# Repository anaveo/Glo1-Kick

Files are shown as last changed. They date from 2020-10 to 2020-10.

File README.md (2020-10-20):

# Glo1-Kick

For more information regarding this project's Kickstarter page, please click [here](https://www.kickstarter.com/projects/omnitech/glo-a-hackable-arduino-based-rgb-led-strip-controller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).

Click [here](https://omanavekar.wixsite.com/ommakes/glo-rev-1) to access the project's main page on [omlabs.me](https://omanavekar.wixsite.com/ommakes)

Glo can be reprogrammed with customizable unique patterns via the Arduino interface. Switching between modes can be done by pressing two buttons on the right side of the board. Since Glo has usable GPIO ports available, LEDs can be controlled by adding external sensors, modules, or communication devices. Glo is also equipped with a hall effect sensor. This device can detect magnetic fields and can be used to change the LED pattern based on magnetic interaction. This can be used for several applications such as sensing if doors or drawers are open or detecting the speed of a bicycle wheel.

## Features
* 4 addressable RGB LED channels
* 1x Digital pin (D2), 8x Analog Pins (A0-A7), and Serial Transmission Pins (TX & RX). However, analog pins may be used as digital pins if necessary. These can be used to wire up other sensors and modules.
* 3x GND pins, 2x 5V pins, 2x 3.3V pins, 1x VIN (voltage supplied by power supply) pin, and 1x RESET pin.
* Open source Arduino-compatible microcontroller (Atmega 328p)
* FT232 USB to Serial converter chip. This chip is used on official Arduino boards and does not contain driver issues commonly found in clones (devices using the CH340G chip).
* Advanced Monolithic Systems AMS1117 Voltage Regulator for microcontroller
* Hall effect sensor. This sensor detects the presence of nearby magnets. For example, this allows for rotation based patterns if Glo is mounted on a bicycle tire.
* Mini USB serial programming port
* Power and status LEDs
* Mini USB 5V power port and terminal block 5-12V power port. Useful for 12V 3pin addressable LEDs
* A 1 amp thermal fuse has been added to the USB Power Port. This is a safety feature meant to prevent damage to your USB power supply as most USB devices have a maximum current   tolerance of 1 amp. In the case that more than 1 amp is drawn from your USB port, the fuse will open the circuit and will reset itself when less than an amp is drawn. If you     would like to bypass the fuse, you can remove it by desoldering the component (marked F1) or soldering a jumper connecting the component's two leads together.

## Compatible LED Types & Maximum LED Control
Glo is designed to work with addressable LEDs/LED strips such as Adafruit Neopixels (SK6812) and WS2812B LEDs (commonly found on addressable LED strips, matrices, etc).

Glo is designed to be powered either via 5V from its USB power port, or 5V from its screw terminal power port. However, the screw terminal power port can accept voltages between 5-12V, meaning addressable LEDs with higher voltages can be controlled using Glo. Glo does not support 4-pin 12V led strips. These strips are not individually addressable and contain an entirely different pinout.

Glo can safely control up to 240 individual LEDs, or 60 LEDs per channel. This allows for control of:

26 feet/8 meters of low-density strips (30 LEDs per meter)
13 feet/4 meters of medium-density strips (60 LEDs per meter)
5.5 feet/1.6 meters of high-density strips (144 LEDs per meter)

## Maximum Current Capability
While control is one thing, power distribution is another issue. Since standard Neopixel/WS2812B LEDs pull ~60mA of current each at maximum brightness (All Red, Green, and Blue sectors on full), 240 LEDs will require 14.4 amps at maximum. While Glo can handle this amount of current, it is not advised to run all 240 LEDs at maximum brightness continuously, as this can overheat both the LEDs and the controller.

It is recommended to keep current usage at 10 amps or below, to protect the electronics involved from overheating. Since most addressable LED projects utilize changing colors and animations, it is likely that this amount of current will never be sourced.

This means that the amount of LEDs that can be powered is dependant on the power supply you plan to use. Make sure that your power supply is capable of supplying the required current for your project before you turn the lights on!

## Important Connection Information
* **DO NOT** connect Glo's USB power port and its Power Terminal to a voltage source at the same time. This may damage the controller as well as both power supplies. 

* Glo has a feature in which it can be programmed while power is supplied through its USB power port or Power Terminal. This allows you to test LED patterns without having to unplug your power source.

* If you are powering Glo via the Power Terminal (2 pin green connector) when programming the device, connect your computer's USB cable to the **PROGRAM PORT ONLY**

    * Connecting your computer's USB to the power port will result in a dual voltage source and could damage your computer's USB port, as well as the controller.
    * All ports and their pinouts have been marked on the underside of the PCB.

* Please connect your LED strips and power supplies based on the pinouts given on the underside of the board. Incorrect wiring may lead to LED damage or failure.

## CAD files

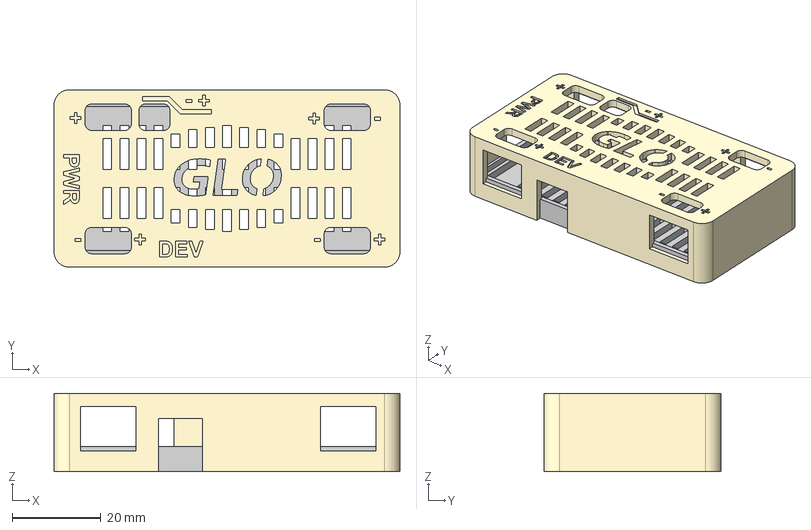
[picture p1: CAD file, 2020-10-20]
models/Case Glo Rev 1.step
78.0 x 40.0 x 17.6 mm

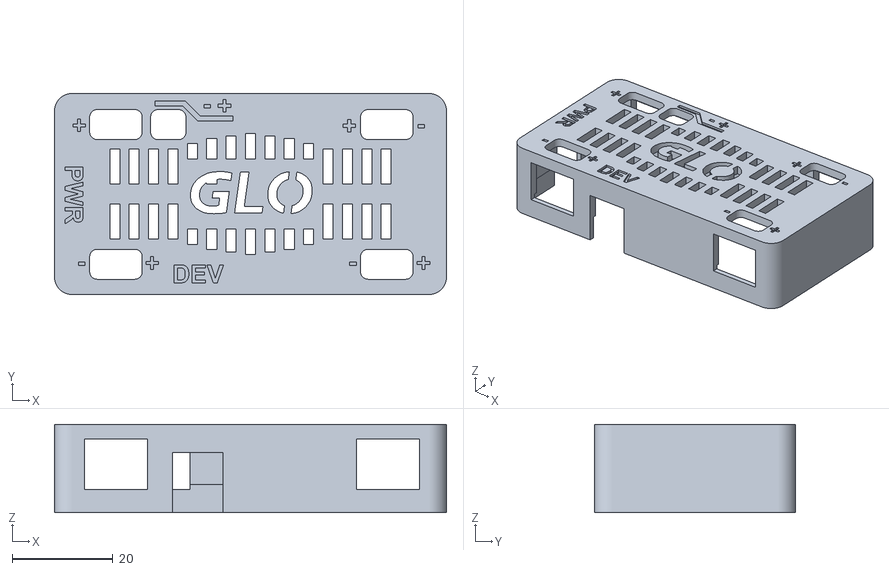
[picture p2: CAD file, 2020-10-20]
models/Glo Case Top.stl
78.0 x 40.0 x 17.6

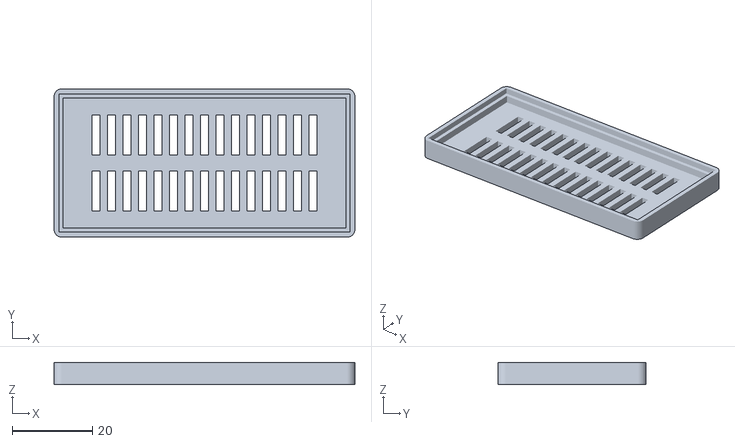
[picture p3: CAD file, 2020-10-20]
models/Glo Case Bottom.stl
75.0 x 37.0 x 5.60

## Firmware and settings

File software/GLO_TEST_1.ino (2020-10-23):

// A basic everyday NeoPixel strip test program.
// Modified for Glo Rev 1 - Om Anavekar

// NEOPIXEL BEST PRACTICES for most reliable operation:
// - Add 1000 uF CAPACITOR between NeoPixel strip's + and - connections.
// - MINIMIZE WIRING LENGTH between microcontroller board and first pixel.
// - NeoPixel strip's DATA-IN should pass through a 300-500 OHM RESISTOR.
// - AVOID connecting NeoPixels on a LIVE CIRCUIT. If you must, ALWAYS
//   connect GROUND (-) first, then +, then data.
// - When using a 3.3V microcontroller with a 5V-powered NeoPixel strip,
//   a LOGIC-LEVEL CONVERTER on the data line is STRONGLY RECOMMENDED.
// (Skipping these may work OK on your workbench but can fail in the field)

#include <Adafruit_NeoPixel.h>
#ifdef __AVR__
 #include <avr/power.h> // Required for 16 MHz Adafruit Trinket
#endif

// Which pin on the Arduino is connected to the NeoPixels?
// On a Trinket or Gemma we suggest changing this to 1:
#define LED_PIN    6
#define LED_PIN2   7
#define LED_PIN3   8
#define LED_PIN4   9

// How many NeoPixels are attached to the Arduino?
#define LED_COUNT 60

// Declare our NeoPixel strip object:
Adafruit_NeoPixel strip(LED_COUNT, LED_PIN, NEO_GRB + NEO_KHZ800);
Adafruit_NeoPixel strip2(LED_COUNT, LED_PIN2, NEO_GRB + NEO_KHZ800);
Adafruit_NeoPixel strip3(LED_COUNT, LED_PIN3, NEO_GRB + NEO_KHZ800);
Adafruit_NeoPixel strip4(LED_COUNT, LED_PIN4, NEO_GRB + NEO_KHZ800);
// Argument 1 = Number of pixels in NeoPixel strip
// Argument 2 = Arduino pin number (most are valid)
// Argument 3 = Pixel type flags, add together as needed:
//   NEO_KHZ800  800 KHz bitstream (most NeoPixel products w/WS2812 LEDs)
//   NEO_KHZ400  400 KHz (classic 'v1' (not v2) FLORA pixels, WS2811 drivers)
//   NEO_GRB     Pixels are wired for GRB bitstream (most NeoPixel products)
//   NEO_RGB     Pixels are wired for RGB bitstream (v1 FLORA pixels, not v2)
//   NEO_RGBW    Pixels are wired for RGBW bitstream (NeoPixel RGBW products)


// setup() function -- runs once at startup --------------------------------

void setup() {
  // These lines are specifically to support the Adafruit Trinket 5V 16 MHz.
  // Any other board, you can remove this part (but no harm leaving it):
#if defined(__AVR_ATtiny85__) && (F_CPU == 16000000)
  clock_prescale_set(clock_div_1);
#endif
  // END of Trinket-specific code.

  strip.begin();           // INITIALIZE NeoPixel strip object (REQUIRED)
  strip.show();            // Turn OFF all pixels ASAP
  strip.setBrightness(50); // Set BRIGHTNESS to about 1/5 (max = 255)
  strip2.begin();           // INITIALIZE NeoPixel strip object (REQUIRED)
  strip2.show();            // Turn OFF all pixels ASAP
  strip2.setBrightness(50);
  strip3.begin();           // INITIALIZE NeoPixel strip object (REQUIRED)
  strip3.show();            // Turn OFF all pixels ASAP
  strip3.setBrightness(50);
  strip4.begin();           // INITIALIZE NeoPixel strip object (REQUIRED)
  strip4.show();            // Turn OFF all pixels ASAP
  strip4.setBrightness(50);
}


// loop() function -- runs repeatedly as long as board is on ---------------

void loop() {
  // Fill along the length of the strip in various colors...
  colorWipe(strip.Color(255,   0,   0), 50); // Red
  colorWipe(strip.Color(  0, 255,   0), 50); // Green
  colorWipe(strip.Color(  0,   0, 255), 50); // Blue

  // Do a theater marquee effect in various colors...
  theaterChase(strip.Color(127, 127, 127), 50); // White, half brightness
  theaterChase(strip.Color(127,   0,   0), 50); // Red, half brightness
  theaterChase(strip.Color(  0,   0, 127), 50); // Blue, half brightness

  rainbow(10);             // Flowing rainbow cycle along the whole strip
  //theaterChaseRainbow(50); // Rainbow-enhanced theaterChase variant
}


// Some functions of our own for creating animated effects -----------------

// Fill strip pixels one after another with a color. Strip is NOT cleared
// first; anything there will be covered pixel by pixel. Pass in color
// (as a single 'packed' 32-bit value, which you can get by calling
// strip.Color(red, green, blue) as shown in the loop() function above),
// and a delay time (in milliseconds) between pixels.
void colorWipe(uint32_t color, int wait) {
  for(int i=0; i<strip.numPixels(); i++) { // For each pixel in strip...
    strip.setPixelColor(i, color);         //  Set pixel's color (in RAM)
    strip.show();                          //  Update strip to match
    strip2.setPixelColor(i, color);         //  Set pixel's color (in RAM)
    strip2.show();  
    strip3.setPixelColor(i, color);         //  Set pixel's color (in RAM)
    strip3.show();  
    strip4.setPixelColor(i, color);         //  Set pixel's color (in RAM)
    strip4.show();  
    delay(wait);                           //  Pause for a moment
  }
}

// Theater-marquee-style chasing lights. Pass in a color (32-bit value,
// a la strip.Color(r,g,b) as mentioned above), and a delay time (in ms)
// between frames.
void theaterChase(uint32_t color, int wait) {
  for(int a=0; a<10; a++) {  // Repeat 10 times...
    for(int b=0; b<3; b++) { //  'b' counts from 0 to 2...
      strip.clear();         //   Set all pixels in RAM to 0 (off)
      strip2.clear(); 
      strip3.clear(); 
      strip4.clear(); 
      // 'c' counts up from 'b' to end of strip in steps of 3...
      for(int c=b; c<strip.numPixels(); c += 3) {
        strip.setPixelColor(c, color); // Set pixel 'c' to value 'color'
        strip2.setPixelColor(c, color);
        strip3.setPixelColor(c, color);
        strip4.setPixelColor(c, color);
      }
      strip.show(); // Update strip with new contents
      strip2.show();
      strip3.show();
      strip4.show();
      delay(wait);  // Pause for a moment
    }
  }
}

// Rainbow cycle along whole strip. Pass delay time (in ms) between frames.
void rainbow(int wait) {
  // Hue of first pixel runs 5 complete loops through the color wheel.
  // Color wheel has a range of 65536 but it's OK if we roll over, so
  // just count from 0 to 5*65536. Adding 256 to firstPixelHue each time
  // means we'll make 5*65536/256 = 1280 passes through this outer loop:
  for(long firstPixelHue = 0; firstPixelHue < 5*65536; firstPixelHue += 256) {
    for(int i=0; i<strip.numPixels(); i++) { // For each pixel in strip...
      // Offset pixel hue by an amount to make one full revolution of the
      // color wheel (range of 65536) along the length of the strip
      // (strip.numPixels() steps):
      int pixelHue = firstPixelHue + (i * 65536L / strip.numPixels());
      // strip.ColorHSV() can take 1 or 3 arguments: a hue (0 to 65535) or
      // optionally add saturation and value (brightness) (each 0 to 255).
      // Here we're using just the single-argument hue variant. The result
      // is passed through strip.gamma32() to provide 'truer' colors
      // before assigning to each pixel:
      strip.setPixelColor(i, strip.gamma32(strip.ColorHSV(pixelHue)));
      strip2.setPixelColor(i, strip2.gamma32(strip2.ColorHSV(pixelHue)));
      strip3.setPixelColor(i, strip3.gamma32(strip3.ColorHSV(pixelHue)));
      strip4.setPixelColor(i, strip4.gamma32(strip4.ColorHSV(pixelHue)));
    }
    strip.show(); // Update strip with new contents
    strip2.show(); // Update strip with new contents
    strip3.show(); // Update strip with new contents
    strip4.show(); // Update strip with new contents
    delay(wait);  // Pause for a moment
  }
}

// Rainbow-enhanced theater marquee. Pass delay time (in ms) between frames.
void theaterChaseRainbow(int wait) {
  int firstPixelHue = 0;     // First pixel starts at red (hue 0)
  for(int a=0; a<30; a++) {  // Repeat 30 times...
    for(int b=0; b<3; b++) { //  'b' counts from 0 to 2...
      strip.clear();         //   Set all pixels in RAM to 0 (off)
      // 'c' counts up from 'b' to end of strip in increments of 3...
      for(int c=b; c<strip.numPixels(); c += 3) {
        // hue of pixel 'c' is offset by an amount to make one full
        // revolution of the color wheel (range 65536) along the length
        // of the strip (strip.numPixels() steps):
        int      hue   = firstPixelHue + c * 65536L / strip.numPixels();
        uint32_t color = strip.gamma32(strip.ColorHSV(hue)); // hue -> RGB
        strip.setPixelColor(c, color); // Set pixel 'c' to value 'color'
      }
      strip.show();                // Update strip with new contents
      delay(wait);                 // Pause for a moment
      firstPixelHue += 65536 / 90; // One cycle of color wheel over 90 frames
    }
  }
}

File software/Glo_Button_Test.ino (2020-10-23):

/*
2 Button Test Code for Glo
Made by Om Anavekar
www.omlabs.me
*/

const int button1 = 4; // button 1
const int button2 = 5; // button 2

//Button state variables
int b1State = 0;
int b2State = 0;

void setup() {
  //Begin Serial Comms
  Serial.begin(9600);

  //Set button pins as inputs
  pinMode(button1, INPUT);
  pinMode(button2, INPUT);
}

void loop() {
  //Read button states
  b1State = digitalRead(button1);
  b2State = digitalRead(button2);

  //If button 1 is pressed, b1State will be HIGH
  if (b1State == HIGH) {
    Serial.println("Button 1 on");
  }
  
  //If button 2 is pressed, b2State will be HIGH
   if (b2State == HIGH) {
    Serial.println("Button 2 on");
   }

delay(100);
}
